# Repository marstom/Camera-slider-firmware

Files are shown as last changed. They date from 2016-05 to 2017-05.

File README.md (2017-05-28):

# Camera-slider-firmware
Stepper motor controller firmware for camera slider, MCU: AtMega32. This software is using to controll 1-axis camera slider using stepper motor. It is designed to work with Cannon photo cameras. Camera must be in Bulb mode, device controll camera shutter. Stepper motor is slow, this device is designed for long timelapses.
### Features:
* Show settings on lcd display,
* Timelapse photos with slide effect,
* User can set timelapse length in hours.

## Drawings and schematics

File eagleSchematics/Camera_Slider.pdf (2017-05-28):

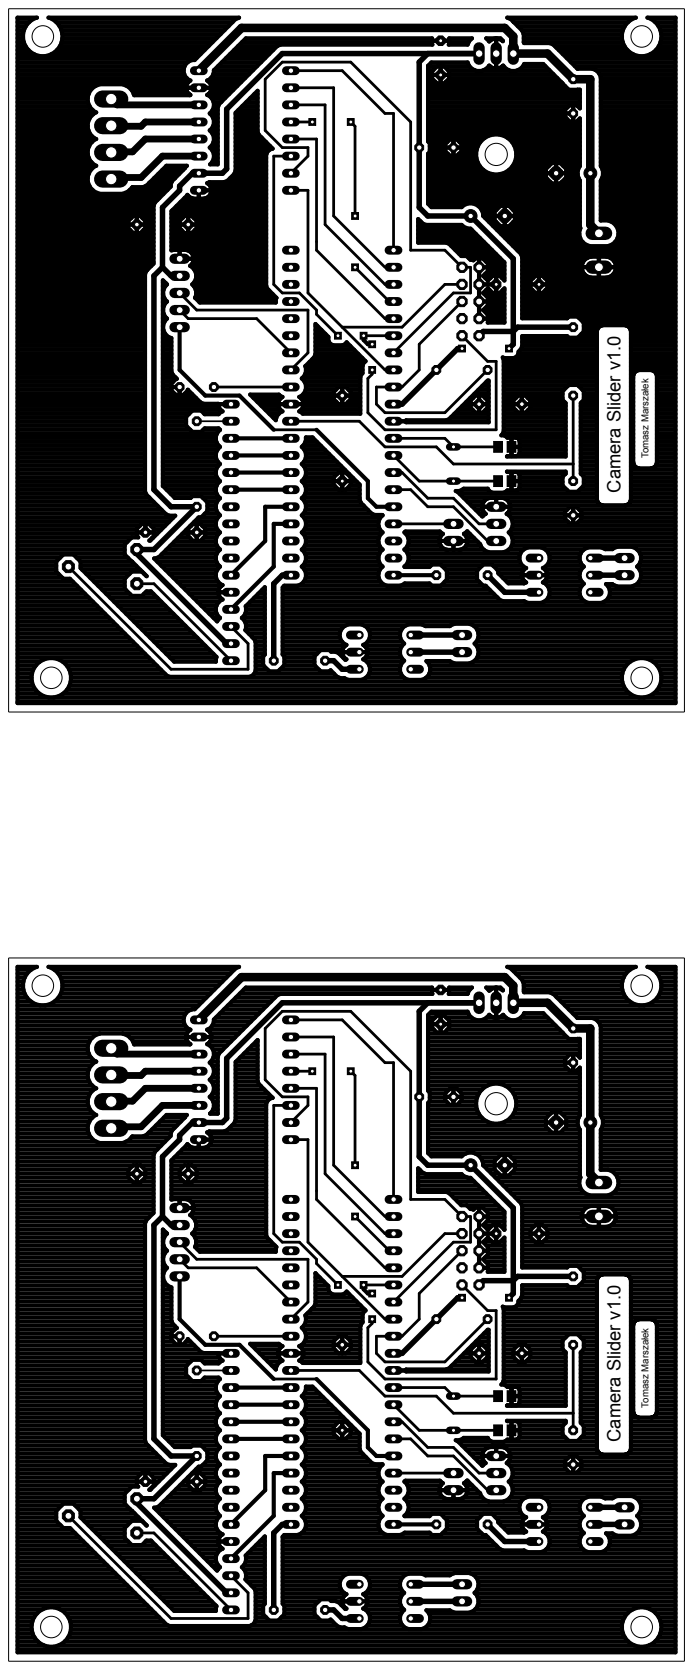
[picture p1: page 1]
Camera Slider v1.0; Tomasz Marszałek

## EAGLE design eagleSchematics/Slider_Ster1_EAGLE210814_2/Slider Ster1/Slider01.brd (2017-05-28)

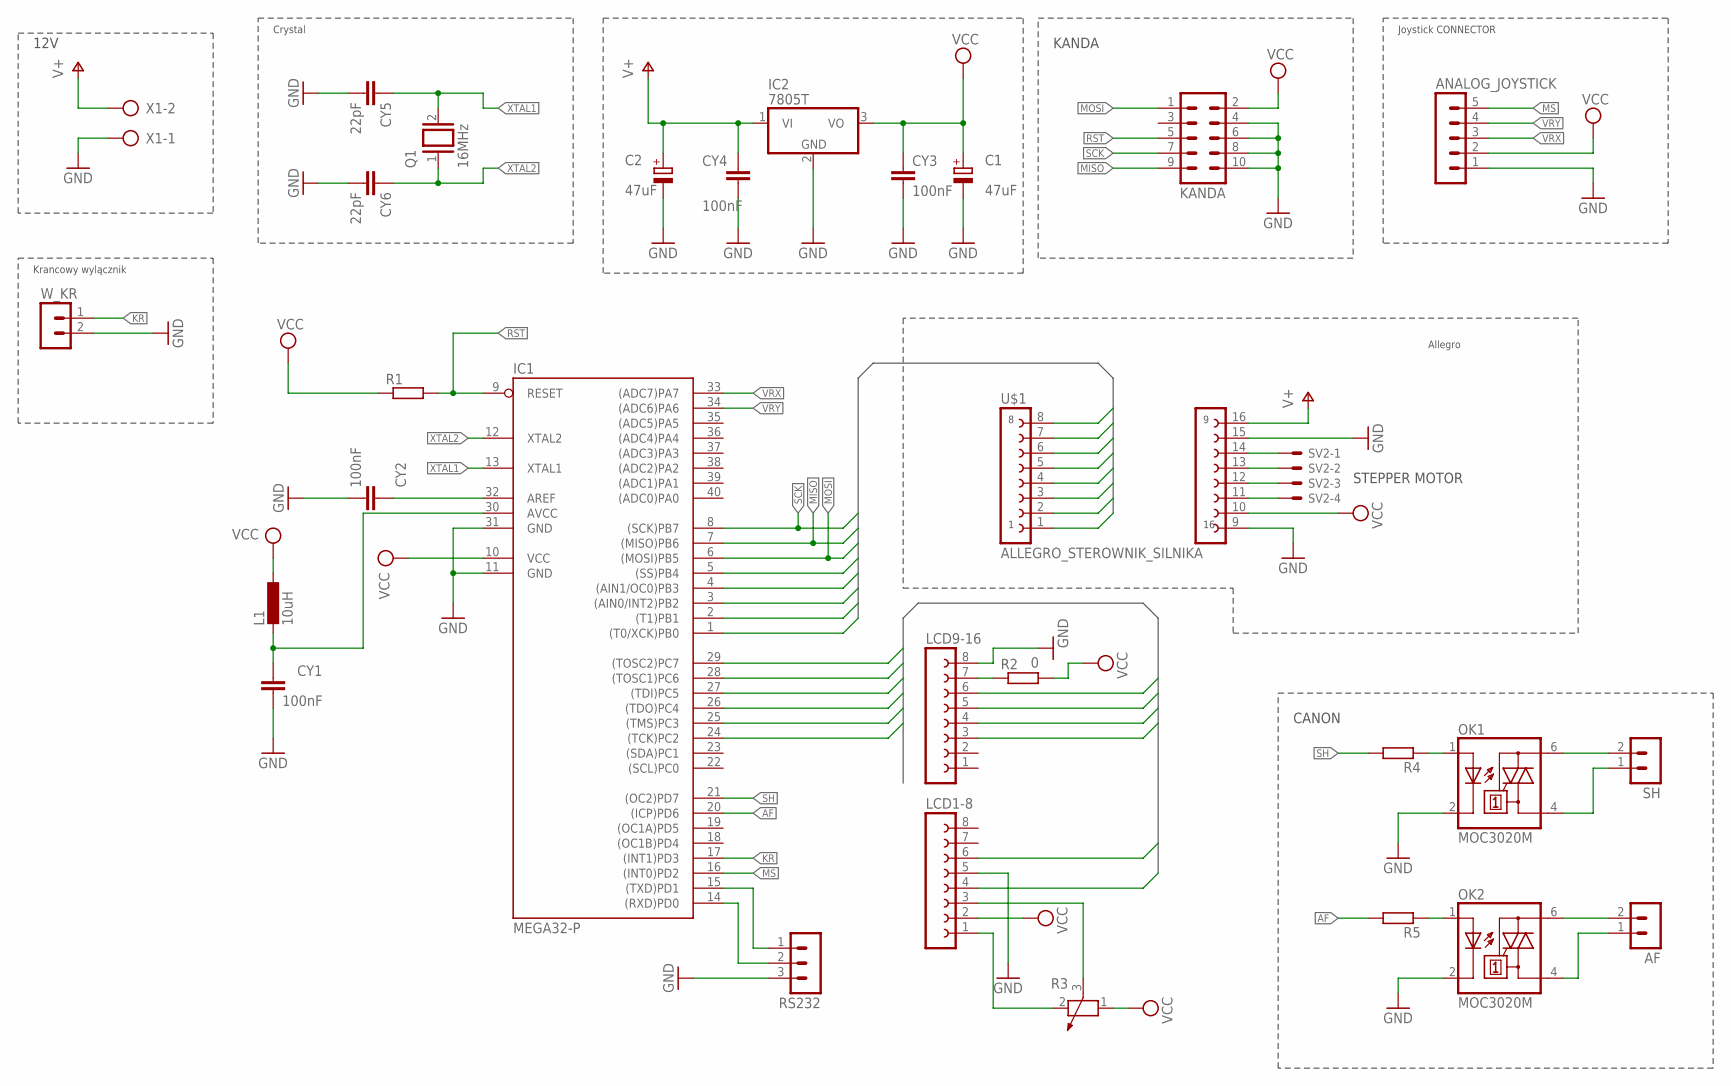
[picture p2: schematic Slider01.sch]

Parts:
AF: LSTB2
ANALOG_JOYSTICK: MA05-1
C1, C2: 47uF; E5-6
CY1, CY2, CY3, CY4: 100nF; C050-024X044
CY5, CY6: 22pF; C1206
IC1: MEGA32-P; DIL40
IC2: 7805T; TO220H
KANDA: MA05-2
L1: 10uH; 0207/10
LCD1-8, LCD9-16: FE08-1; FE08
OK1, OK2: MOC3020M; DIL06
Q1: 16MHz; QS
R1, R4, R5: R-EU_0207/7; 0207/7
R2: 0; 0207/12
R3: POTENTIOMETER_PT-10; PT-10
RS232: MA03-1
SH: LSTB2
SV2: KK-156-4
U$1: ALLEGRO_STEROWNIK_SILNIKA; ALLEGRO_STEROWNIK
W_KR: LSTB2
X1: AK500/2

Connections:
#E: IC1.25 ((TMS)PC3), LCD1-8.6
AF: IC1.20 ((ICP)PD6), R5.2
D4: IC1.26 ((TDO)PC4), LCD9-16.3
D5: IC1.27 ((TDI)PC5), LCD9-16.4
D6: IC1.28 ((TOSC1)PC6), LCD9-16.5
D7: IC1.29 ((TOSC2)PC7), LCD9-16.6
GND: ANALOG_JOYSTICK.1, C1.-, C2.-, CY1.2, CY2.2, CY3.2, CY4.2, CY5.2, CY6.2, IC1.11 (GND), IC1.31 (GND), IC2.2 (GND), KANDA.4, KANDA.6, KANDA.8, KANDA.10, LCD1-8.5, LCD9-16.8, OK1.2 (C), OK2.2 (C), RS232.3, U$1.9 (A16), U$1.15 (A10), W_KR.2, X1.1
KR: IC1.17 ((INT1)PD3), W_KR.1
MISO: IC1.7 ((MISO)PB6), KANDA.9, U$1.7
MOSI: IC1.6 ((MOSI)PB5), KANDA.1, U$1.6
MS: ANALOG_JOYSTICK.5, IC1.16 ((INT0)PD2)
unnamed: SV2.1, U$1.14 (A11)
unnamed: SV2.2, U$1.13 (A12)
unnamed: SV2.3, U$1.12 (A13)
unnamed: SV2.4, U$1.11 (A14)
unnamed: LCD9-16.7, R2.1
unnamed: CY2.1, IC1.32 (AREF)
unnamed: CY1.1, IC1.30 (AVCC), L1.2
unnamed: LCD1-8.1, R3.2
unnamed: LCD1-8.3, R3.3
unnamed: OK1.1 (A), R4.1
unnamed: OK2.1 (A), R5.1
unnamed: OK1.6 (A2), SH.2
unnamed: OK1.4 (A1), SH.1
unnamed: AF.2, OK2.6 (A2)
unnamed: AF.1, OK2.4 (A1)
unnamed: IC1.15 ((TXD)PD1), RS232.1
unnamed: IC1.14 ((RXD)PD0), RS232.2
PB0: IC1.1 ((T0/XCK)PB0), U$1.1
PB1: IC1.2 ((T1)PB1), U$1.2
PB2: IC1.3 ((AIN0/INT2)PB2), U$1.3
PB3: IC1.4 ((AIN1/OC0)PB3), U$1.4
PB4: IC1.5 ((SS)PB4), U$1.5
RS: IC1.24 ((TCK)PC2), LCD1-8.4
RST: IC1.9 (RESET), KANDA.5, R1.2
SCK: IC1.8 ((SCK)PB7), KANDA.7, U$1.8
SH: IC1.21 ((OC2)PD7), R4.2
V+: C2.+, CY4.1, IC2.1 (VI), U$1.16 (A9), X1.2
VCC: ANALOG_JOYSTICK.2, C1.+, CY3.1, IC1.10 (VCC), IC2.3 (VO), KANDA.2, L1.1, LCD1-8.2, R1.1, R2.2, R3.1, U$1.10 (A15)
VRX: ANALOG_JOYSTICK.3, IC1.33 ((ADC7)PA7)
VRY: ANALOG_JOYSTICK.4, IC1.34 ((ADC6)PA6)
XTAL1: CY5.1, IC1.13 (XTAL1), Q1.2
XTAL2: CY6.1, IC1.12 (XTAL2), Q1.1

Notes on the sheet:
KANDA
STEPPER MOTOR
Joystick CONNECTOR
Crystal
Allegro
CANON
Krancowy wylącznik
12V

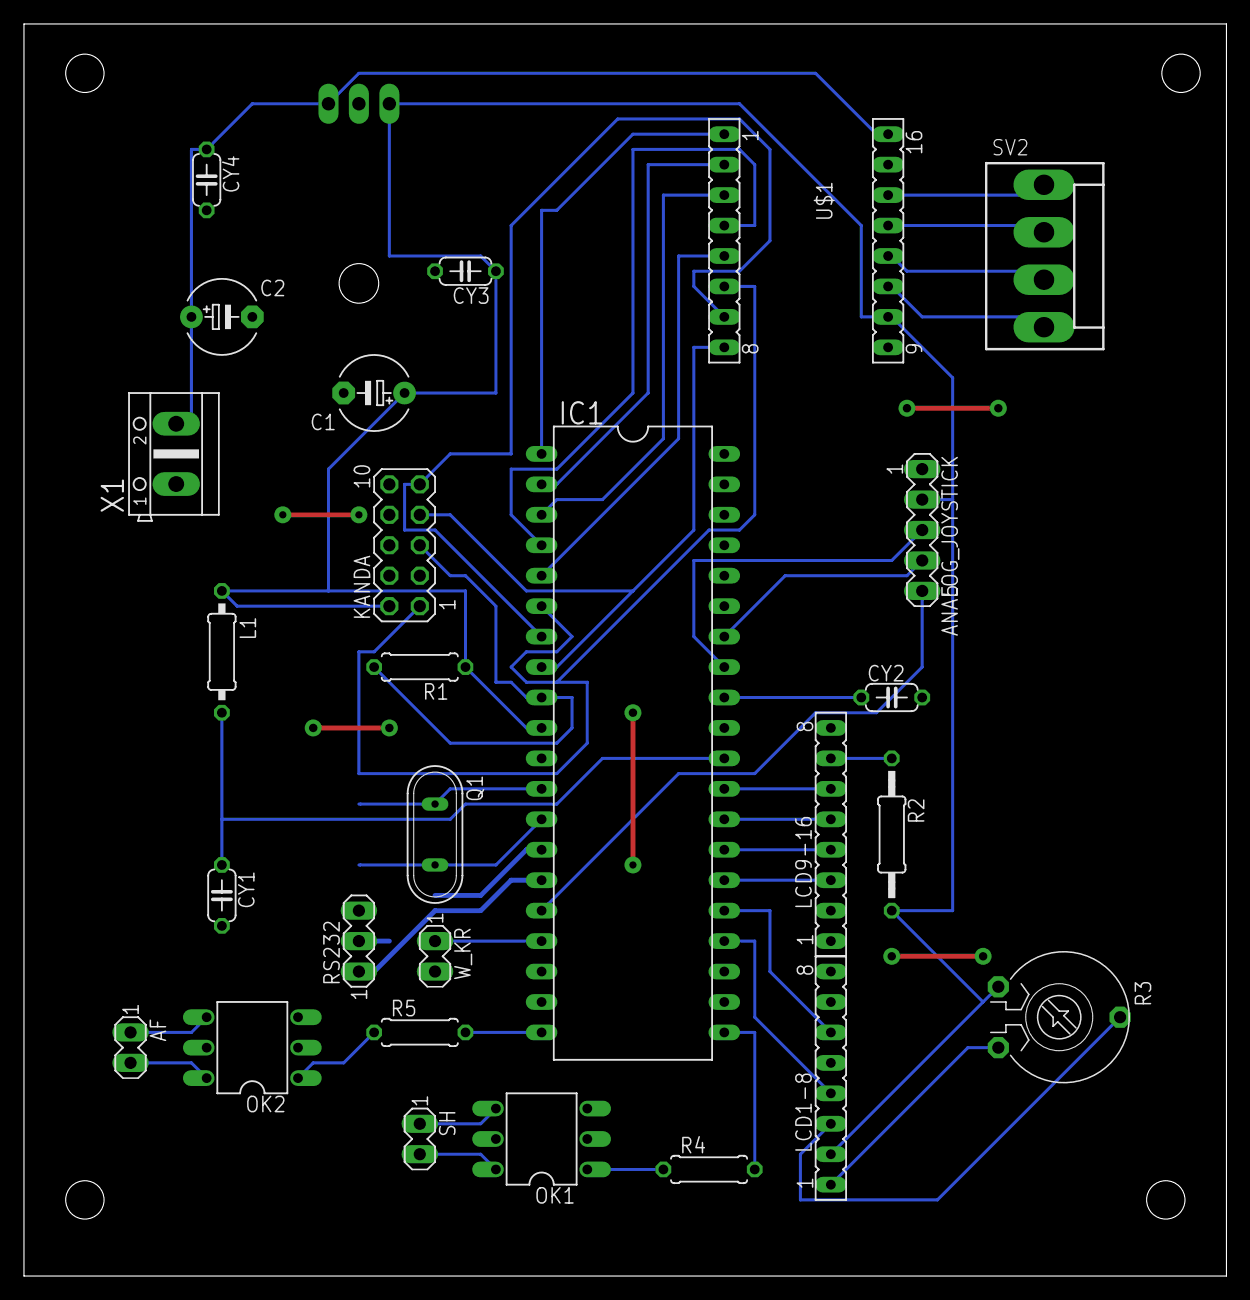
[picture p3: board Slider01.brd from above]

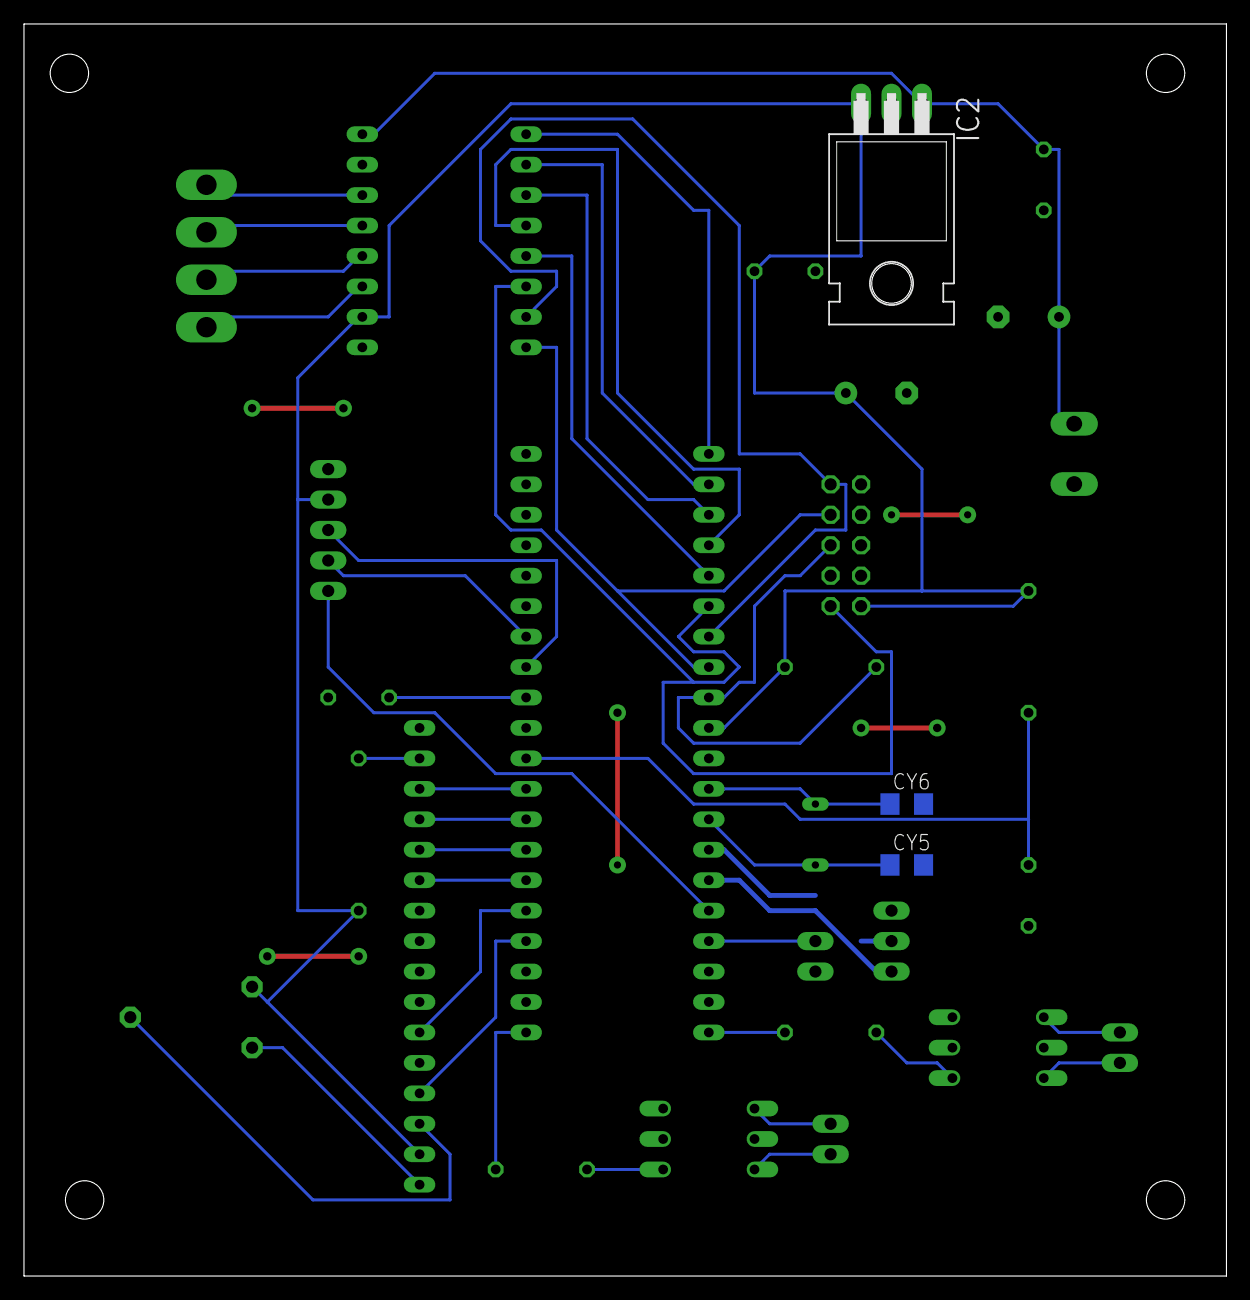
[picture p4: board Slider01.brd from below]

Board: 2 copper layers, 100.3 x 104.4 mm, 30 parts (3 on the bottom side), 43 nets.

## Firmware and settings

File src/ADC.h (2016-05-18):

/*
Przetwornik AC
*/
#include <avr/io.h>

#define ADC_ENABLE 					ADCSRA |= (1<<ADEN)
#define ADC_DISABLE 				ADCSRA &= 0x7F
#define ADC_START_CONVERSION		ADCSRA |= (1<<ADSC)
#define CHANNEL_X                     PORT7 // z którego pinu czytaæ napiêcie
#define CHANNEL_Y                     PORT6 // z którego pinu czytaæ napiêcie

int read_X(void);
int read_Y(void);
void ADC_init(void);
int ADC_Read(void);

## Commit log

2016-05-18 Camera slider firmware v0.13
2017-05-28 Add schematics and board design PCB
    [Slider01.brd, Slider01.sch]
